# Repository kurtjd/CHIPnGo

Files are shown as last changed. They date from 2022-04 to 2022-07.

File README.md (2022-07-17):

# CHIPnGo
|Current Status|
|--------------|
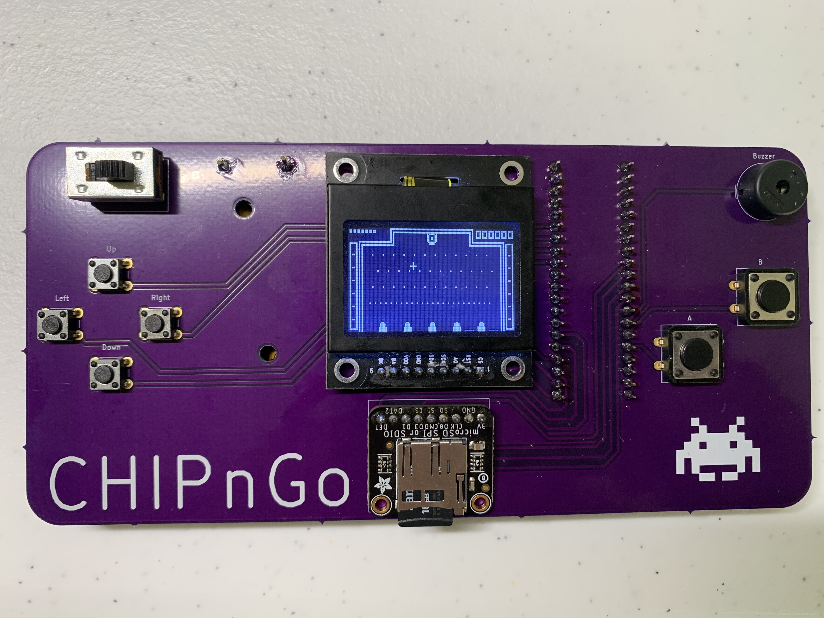
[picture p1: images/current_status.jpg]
||

Recently I've taken a serious interest in embedded development, so I decided for my first project I would attempt to port my [CHIP-8 emulator](https://github.com/kurtjd/jaxe) to a STM32 microcontroller in order to eventually build a CHIP-8 hand-held gaming console. Since this is being done as a learning experience, I also decided I would do this bare-metal with no libraries and write all drivers from scratch. While this is proving to be slow and extremely frustrating at times, it has also been very insightful and I've already learned a ton in such a short time.

[See it in action!](https://www.youtube.com/watch?v=SVods0DDVes)

## Build Guide
If you are interested in building your own CHIPnGo, check out [this guide](https://kurtjd.github.io/2022/07/16/chipngo-build-guide/).

## Development Blog
If you are interested in reading about my development of the project, some challenges I faced, and the bone-headed design decisions I made along the way due to my inexperience, check out my [dev blog](https://kurtjd.github.io/2022/07/08/chipngo-dev-1-intro/).

## Features
- Fully supports all CHIP-8 and S-CHIP ROMs
- LCD graphical display
- Four directional buttons and two action buttons
- Piezo buzzer for simple tone generation
- SD card reader for quick loading of any CHIP-8 ROM
- Battery power
- [Desktop application to manage ROMs on an SD card (aka game cartridge)](tools/cartridge8/)

## ToDo
- Improve startup menu for user to select ROM via SD card (make a bit more pretty)
- Improve startup splash screen (want something cool and animated)
- Iron out minor firmware bugs

## Limitations
Although my original emulator also has full support for XO-CHIP roms, I decided to focus on just CHIP-8 and S-CHIP for now for several reasons:
- XO-CHIP ROMs expect up to 64kb of memory, as opposed to 4kb expected by original CHIP-8 ROMs.
- XO-CHIP supports up to three colors, which would mean needing to move beyond a simple monochrome display.
- XO-CHIP supports variable frequencies/tones whereas CHIP-8 ROMs can only produce a single frequency, which makes handling sound simple.

CHIP-8 supports 16 keys for input, however for design purposes, the console only has 6 buttons.
However, most games only use a few buttons so this isn't too much of an issue.

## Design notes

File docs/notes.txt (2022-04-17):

CHIPnGo
-------
Handheld CHIP8 game console using JAXE emulator

To-Do
-----
-Write SPI driver
-Use Nokia 5110 for display testing
-Wire up actual display
-Write driver for actual display
-Test throughly
-Wire in buzzer
-Write code to generate sound
-Wire in SD reader
-Write SD reader driver
-Write code to read ROMs and configs from SD
-Write code to save userflags in Flash memory
-Write menu, boot splash, etc
-Figure out battery power situation
-Add switch to turn board on/off
-Look into prototype board to solder all together
-Look into building case

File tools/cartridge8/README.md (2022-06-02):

# Cartridge8
|ROM Selection|ROM Edit|
|---|---|
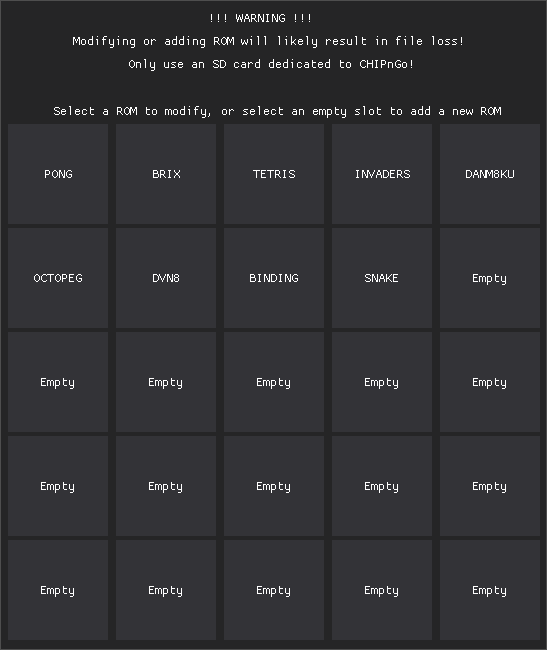
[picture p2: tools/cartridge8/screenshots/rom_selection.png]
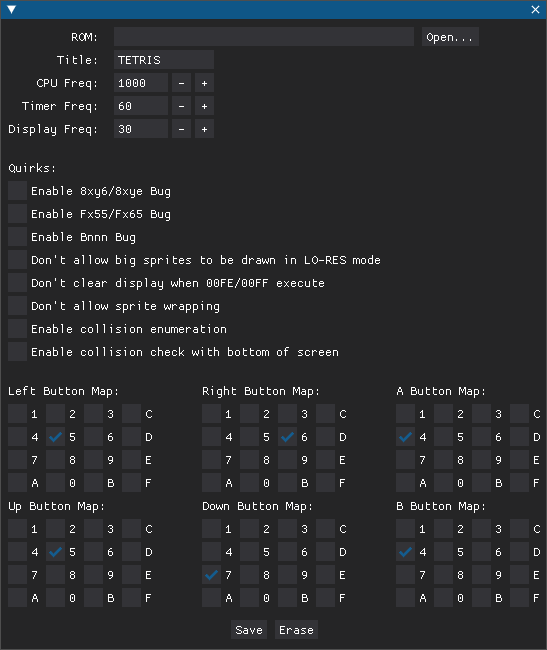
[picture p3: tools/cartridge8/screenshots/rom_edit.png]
|||

A tool for adding and configuring CHIP-8 ROMs to an SD card (aka game cartridge)
 for use by the CHIPnGo game console.
 
 ## Requirements
 - Python 3+
 - All requirements in requirements.txt
 
 ## Installation
 ```pip install -r requirements.txt```
 
 ## Run
 ```python cartridge8.py <path-to-SD-card>```
 
 ## Instructions
 - Insert an SD card (dedicated to CHIPnGo, see Warning) before running
 - After starting script, you will be presented with a ROM selection window
 - Select an existing ROM to modify, or an Empty slot to add a new ROM
 - Click Save to write your changes to SD, or Erase to erase the ROM from the SD
 
 ## WARNING
 This tool performs raw writes to your SD card and disregards any kind of file system already on there. 
 Thus, existing files are likely to be erased or corrupted after using this tool. ONLY use an SD card dedicated to 
 CHIPnGo to avoid data loss!

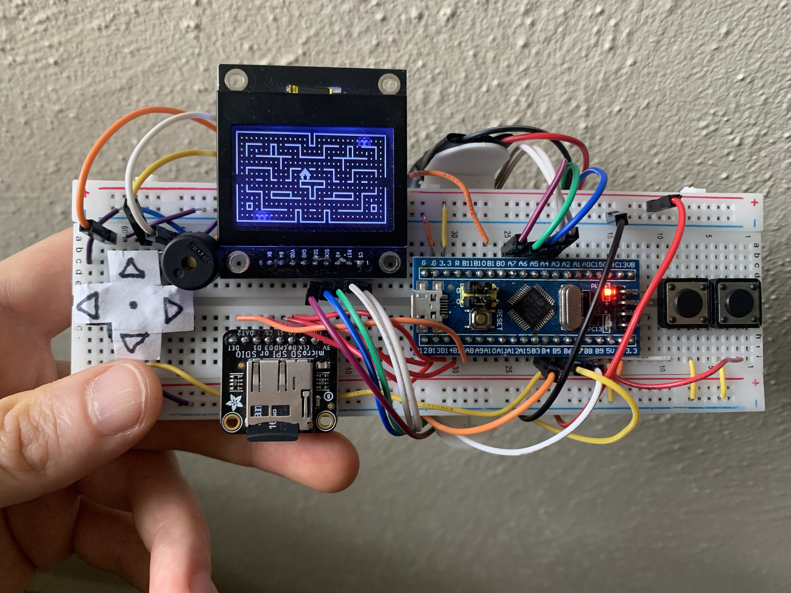
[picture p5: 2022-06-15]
images/current_status_6.jpg

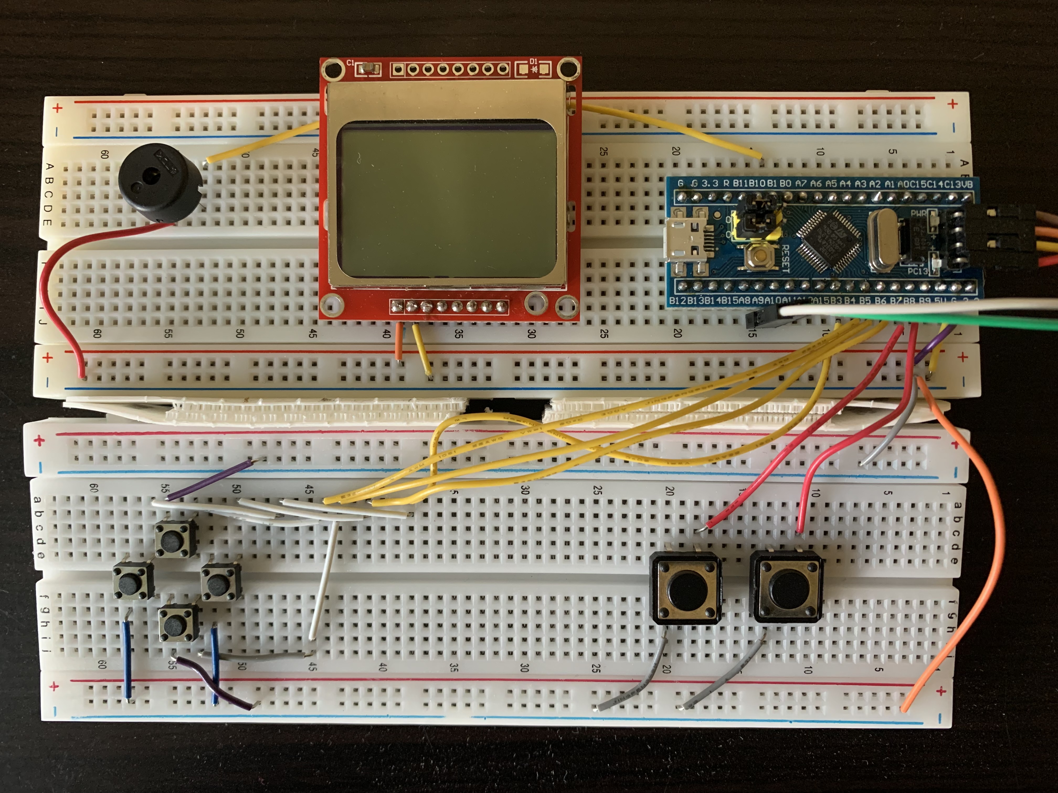
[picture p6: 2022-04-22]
images/current_status_2.jpg

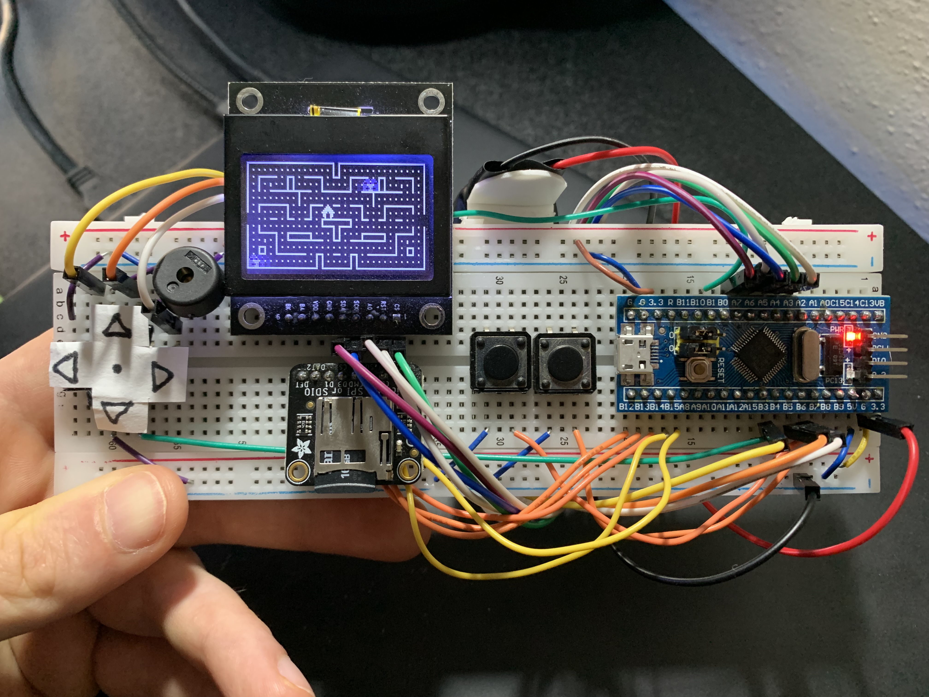
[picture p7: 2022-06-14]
images/current_status_5.jpg

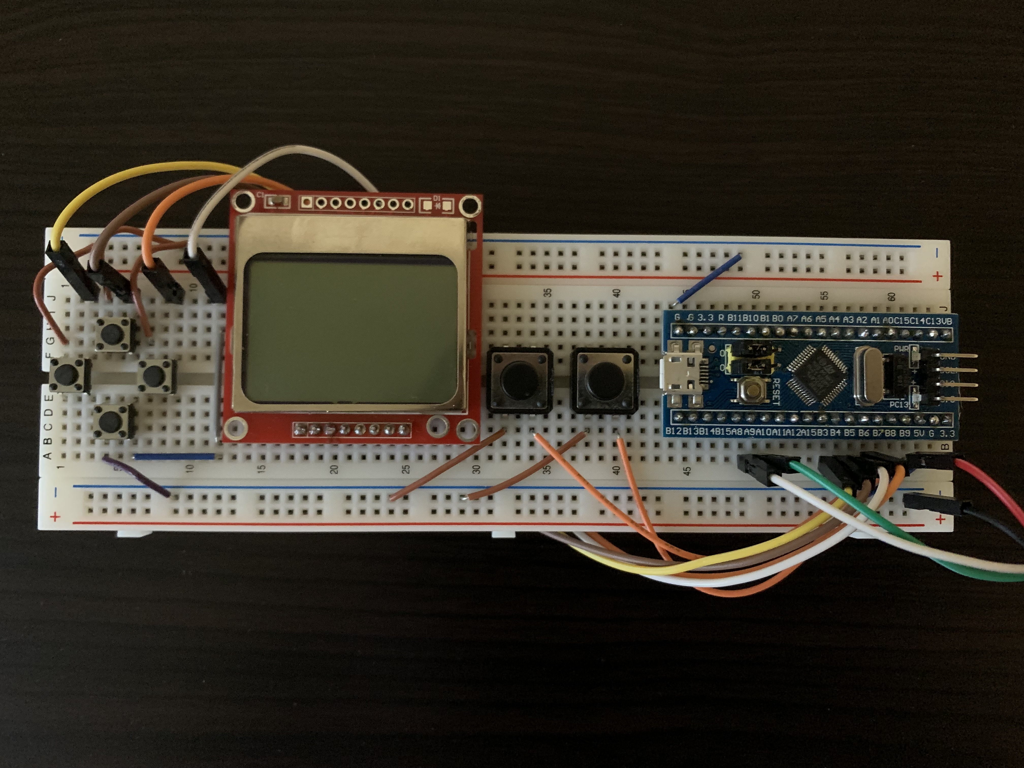
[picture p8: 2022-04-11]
images/current_status_1.jpg

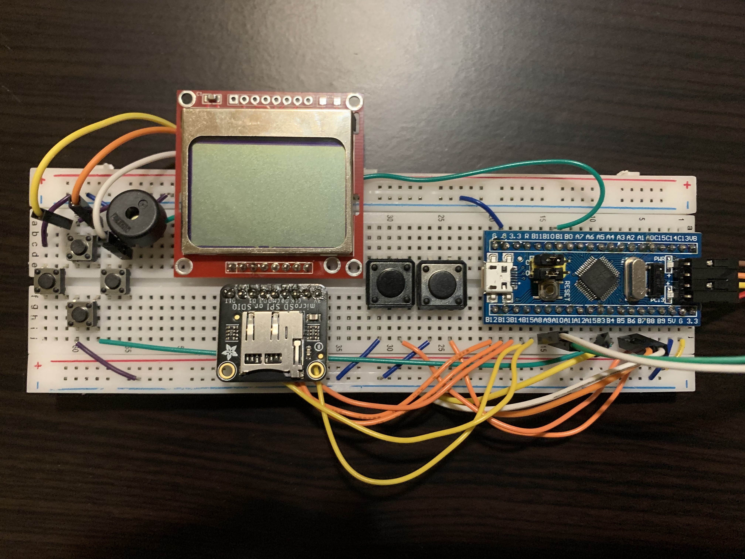
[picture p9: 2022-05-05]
images/current_status_3.jpg

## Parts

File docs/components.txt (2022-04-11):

Board: STM32F103 ($4)
Display: 1.5" 128x64 SPI ($4)
SD Reader:
Battery:
Case:
Piezo Buzzer:
Buttons: ($0.75)
Switch:
LED:
Wire:
Resistors:

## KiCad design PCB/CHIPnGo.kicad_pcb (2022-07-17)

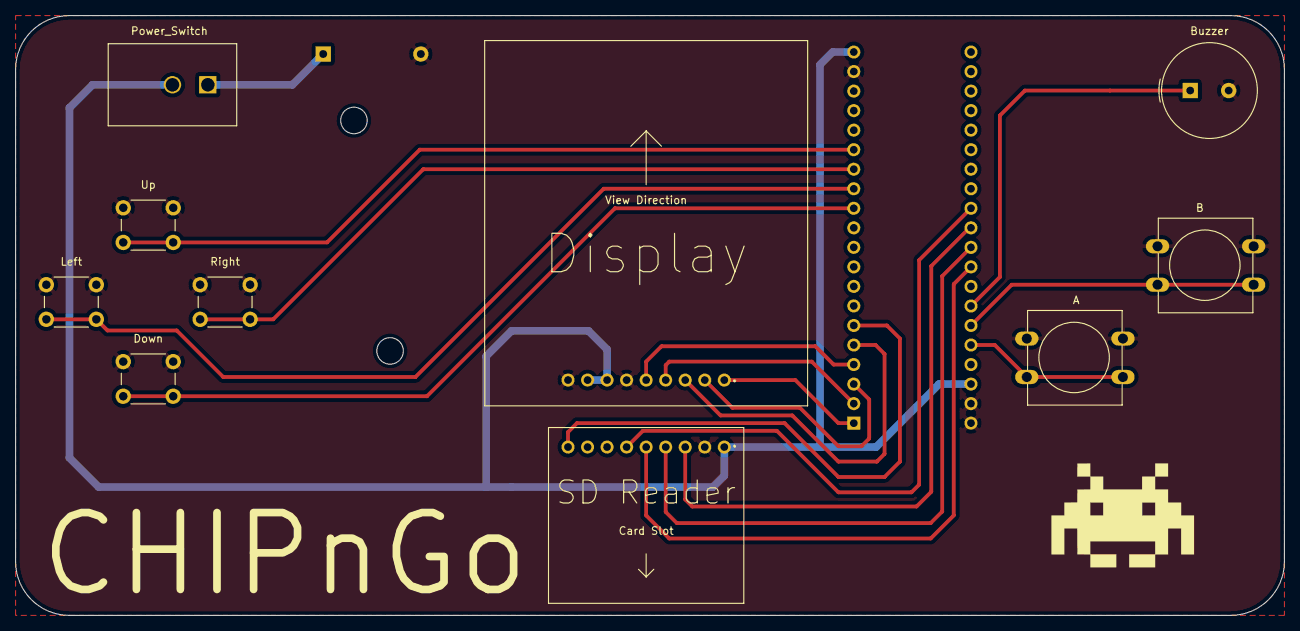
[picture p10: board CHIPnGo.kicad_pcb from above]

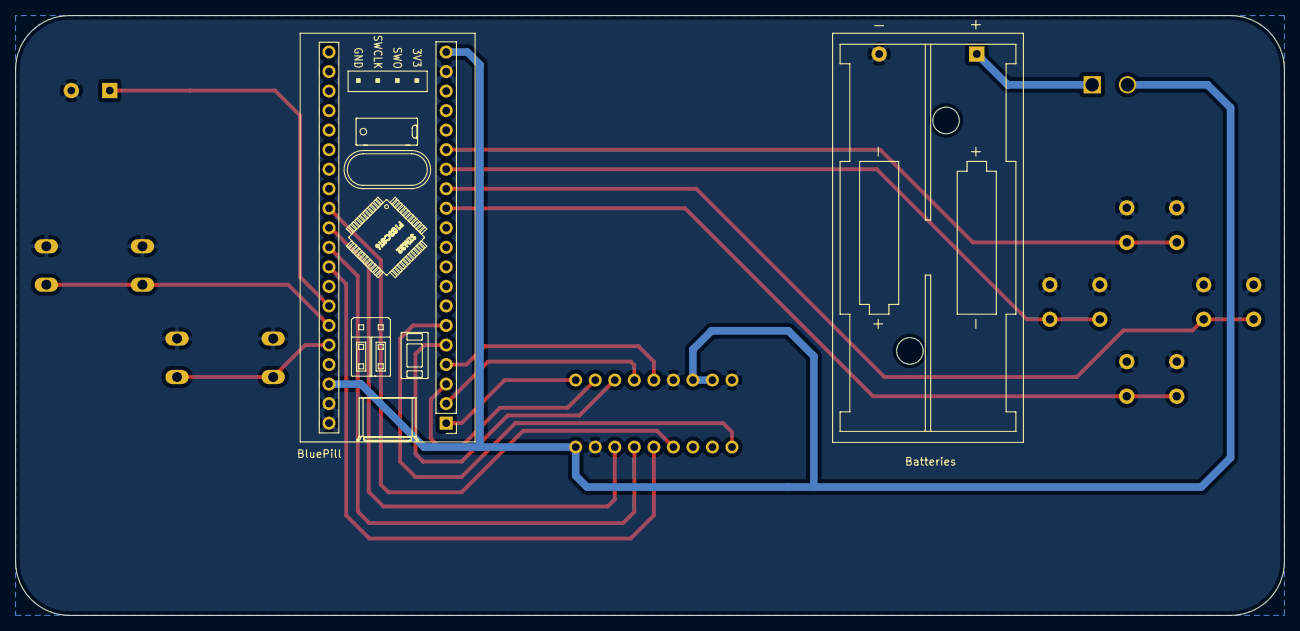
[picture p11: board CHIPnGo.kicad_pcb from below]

Board: 2 copper layers, 165.0 x 78.0 mm, 12 parts (2 on the bottom side), 20 nets.

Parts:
A: A_Btn; SW_PUSH-12mm
B: B_Btn; SW_PUSH-12mm
Batteries: Batteries; BatteryHolder_Keystone_2468_2xAAA
BluePill: STM32_BluePill; YAAJ_BluePill_1
Buzzer: Piezo_Buzzer; Buzzer_TDK_PS1240P02BT_D12.2mm_H6.5mm
Display: ERM12864-8_Display; ERM12864
Down: Down_Btn; SW_PUSH_6mm_H5mm
Left: Left_Btn; SW_PUSH_6mm_H5mm
Power_Switch: Power_Switch; GF-123-0054
Right: Right_Btn; SW_PUSH_6mm_H5mm
SD Reader: Adafruit_MicroSD_Breakout; Adafruit_SD_Reader
Up: Up_Btn; SW_PUSH_6mm_H5mm

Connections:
+3V3: BluePill.20, BluePill.38, Display.7, Display.8, Power_Switch.2, SD Reader.1
/Card_Det: BluePill.6, SD Reader.9
GND: A.2, B.2, Batteries.2, BluePill.19, BluePill.39, BluePill.40, Buzzer.2, Display.6, Display.9, Down.1, Left.1, Right.1, SD Reader.2, Up.1
unnamed: Batteries.1, Power_Switch.1
unnamed: BluePill.34, Buzzer.1
unnamed: BluePill.13, Left.2
unnamed: BluePill.12, Down.2
unnamed: BluePill.15, Up.2
unnamed: BluePill.14, Right.2
unnamed: A.1, BluePill.36
unnamed: B.1, BluePill.35
unnamed: BluePill.30, SD Reader.3
unnamed: BluePill.31, SD Reader.4
unnamed: BluePill.32, SD Reader.5
unnamed: BluePill.29, SD Reader.6
unnamed: BluePill.1, Display.1
unnamed: BluePill.2, Display.4
unnamed: BluePill.3, Display.2
unnamed: BluePill.4, Display.5
unnamed: BluePill.5, Display.3

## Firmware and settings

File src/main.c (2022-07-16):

#include <stdbool.h>
#include <stdint.h>
#include <stdio.h>
#include <string.h>

#include "buttons.h"
#include "chip8.h"
#include "clock.h"
#include "delay.h"
#include "display.h"
#include "gpio.h"
#include "led.h"
#include "pwm.h"
#include "sd.h"
#include "sysclk.h"
#include "uart.h"

#define MAX_ROMS 25

// Emulator (TODO: Put this all in struct)
CHIP8 chip8;
uint8_t metadata[SD_BLOCK_SIZE] = {0};
char title[11];
uint32_t cpu_freq = CPU_FREQ_DEFAULT;
uint32_t timer_freq = TIMER_FREQ_DEFAULT;
uint32_t refresh_freq = REFRESH_FREQ_DEFAULT;
bool quirks[NUM_QUIRKS] = {0, 0, 0, 0, 0, 0, 0, 0};
uint16_t BTN_LEFT_MAP = 0x90;
uint16_t BTN_RIGHT_MAP = 0x240;
uint16_t BTN_UP_MAP = 0x20;
uint16_t BTN_DOWN_MAP = 0x100;
uint16_t BTN_A_MAP = 0x00;
uint16_t BTN_B_MAP = 0x40;
bool play_sound = false;
int rom_num = 0;

// A basic splash screen that waits for user to press A
void show_splash(void) {
    display_print(37, 4, "CHIP N GO");
    // display_print(20, 4, "PRESS A TO PLAY");
    // display_print(20, 7, "CREATED BY KURT");

    for (int i = 0; i < 10; i++) {
        pwm_start();
        delay(100);
        pwm_stop();
        delay(100);
    }

    display_clear();

    // while (!btn_released(BTN_A));
    // delay(2000);
}

void btn_to_key(uint16_t btn_map, CHIP8K action) {
    for (int i = 0; i < 16; i++) {
        if (btn_map & 1)
            chip8.keypad[i] = action;
        btn_map >>= 1;
    }
}

void parse_quirks(uint8_t q) {
    for (int i = 0; i < 8; i++) {
        quirks[i] = q & 1;
        q >>= 1;
    }
}

// Set up the emulator to begin running.
bool init_emulator(void) {
    chip8_init(&chip8, cpu_freq, timer_freq, refresh_freq, PC_START_ADDR_DEFAULT,
               quirks, metadata, rom_num);
    chip8_load_font(&chip8);

    return true;
}

void load_rom(int rom_num) {
    uint32_t start_sector = rom_num * 8;
    sd_read_block(start_sector, metadata);
    sd_read_blocks(start_sector + 1, chip8.RAM + PC_START_ADDR_DEFAULT, 7);
}

bool process_metadata(void) {
    if (metadata[0] == 0xC8) {
        strcpy(title, (char *)(&metadata[1]));

        cpu_freq = (metadata[12] << 24) | (metadata[13] << 16) | (metadata[14] << 8) | (metadata[15]);
        timer_freq = metadata[16];
        refresh_freq = metadata[17];

        parse_quirks(metadata[18]);

        BTN_LEFT_MAP = (metadata[19] << 8) | (metadata[20]);
        BTN_RIGHT_MAP = (metadata[21] << 8) | (metadata[22]);
        BTN_UP_MAP = (metadata[23] << 8) | (metadata[24]);
        BTN_DOWN_MAP = (metadata[25] << 8) | (metadata[26]);
        BTN_A_MAP = (metadata[27] << 8) | (metadata[28]);
        BTN_B_MAP = (metadata[29] << 8) | (metadata[30]);

        return true;
    }

    return false;
}

// Very slow... but functional for now
bool seek_rom(int dir) {
    int attempts = 0;

    do {
        if (rom_num >= MAX_ROMS)
            rom_num = 0;
        else if (rom_num < 0)
            rom_num = MAX_ROMS - 1;

        load_rom(rom_num);
        rom_num += dir;

        attempts++;
    } while (attempts <= MAX_ROMS && !process_metadata());

    if (attempts <= MAX_ROMS) {
        rom_num -= dir;
        return true;
    }

    // No ROM exists if we attempted to find a ROM more than MAX_ROMS times
    return false;
}

void select_rom(void) {
    int scan_dir = 1;
    bool rom_exists = seek_rom(scan_dir);

    while (rom_exists) {
        display_clear();
        display_print(36 + ((10 - strlen(title)) * 2), 3, title);
        display_print(2, 4, "<                   >");
        display_print(19, 5, "PRESS A TO PLAY");

        scan_dir = 0;
        while (!scan_dir) {
            if (btn_released(BTN_A)) {
                pwm_start();
                delay(500);
                pwm_stop();
                return;
            } else if (btn_released(BTN_RIGHT))
                scan_dir = 1;
            else if (btn_released(BTN_LEFT))
                scan_dir = -1;
        }
        rom_num += scan_dir;

        pwm_start();
        delay(1);
        pwm_stop();

        rom_exists = seek_rom(scan_dir);
    }

    // No ROM exists on game cartridge
    // Just hang since no way to recover
    display_clear();
    display_print(25, 4, "ROM NOT FOUND");
    while (1)
        ;
}

// Makes the physical screen match the emulator display.
void draw_display(void) {
    display_draw(chip8.display);
}

// Handles sound.
void handle_sound(void) {
    if (!play_sound && chip8.beep) {
        pwm_start();
        play_sound = true;
    } else if (play_sound && !chip8.beep) {
        pwm_stop();
        play_sound = false;
    }
}

// Handles drawing the display.
void handle_display(void) {
    if (chip8.display_updated) {
        draw_display();
    }
}

// Checks for key presses/releases and a quit event.
void handle_input(void) {
    if (btn_pressed(BTN_LEFT))
        btn_to_key(BTN_LEFT_MAP, KEY_DOWN);
    if (btn_pressed(BTN_UP))
        btn_to_key(BTN_UP_MAP, KEY_DOWN);
    if (btn_pressed(BTN_DOWN))
        btn_to_key(BTN_DOWN_MAP, KEY_DOWN);
    if (btn_pressed(BTN_RIGHT))
        btn_to_key(BTN_RIGHT_MAP, KEY_DOWN);
    if (btn_pressed(BTN_A))
        btn_to_key(BTN_A_MAP, KEY_DOWN);
    if (btn_pressed(BTN_B))
        btn_to_key(BTN_B_MAP, KEY_DOWN);

    if (btn_released(BTN_LEFT))
        btn_to_key(BTN_LEFT_MAP, KEY_RELEASED);
    if (btn_released(BTN_UP))
        btn_to_key(BTN_UP_MAP, KEY_RELEASED);
    if (btn_released(BTN_DOWN))
        btn_to_key(BTN_DOWN_MAP, KEY_RELEASED);
    if (btn_released(BTN_RIGHT))
        btn_to_key(BTN_RIGHT_MAP, KEY_RELEASED);
    if (btn_released(BTN_A))
        btn_to_key(BTN_A_MAP, KEY_RELEASED);
    if (btn_released(BTN_B))
        btn_to_key(BTN_B_MAP, KEY_RELEASED);
}

void echo_sd_read(uint32_t addr) {
    uint8_t data[SD_BLOCK_SIZE * 2] = {0};
    sd_read_blocks(addr, data, 2);

    for (int i = 0; i < SD_BLOCK_SIZE * 2; i++) {
        char msg[7] = {0};
        sprintf(msg, "0x%02X ", data[i]);

        if ((i + 1) % 16 == 0)
            msg[5] = '\n';

        uart_write_str(msg);
    }

    uart_write('\n');
}

void handle_sd() {
    // Wait for user to insert SD card
    if (!sd_inserted()) {
        display_print(2, 4, "INSERT GAME CARTRIDGE");
        while (!sd_inserted())
            ;

        // Wait briefly for SD to be fully inserted
        display_clear();
        delay(100);
    }

    // Can't recover so just hang and tell the user to restart
    if (!sd_init()) {
        display_print(5, 3, "GAME CARTRIDGE ERROR");
        display_print(22, 4, "PLEASE RESTART");
        while (1)
            ;
    }
}

int main(void) {
    set_sysclk(72);

    gpio_init(GPIOA);
    gpio_init(GPIOB);
    led_enable();

    pwm_init(880);

    display_init();
    show_splash();

    handle_sd();

    buttons_init();

    clock_start();

    select_rom();
    init_emulator();

    while (1) {
        handle_input();
        chip8_cycle(&chip8);
        handle_sound();
        handle_display();

        // Exit gets set true if the ROM calls the exit command
        if (chip8.exit)
            chip8_reset(&chip8);
    }

    return 0;
}

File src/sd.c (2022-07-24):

#include "sd.h"

#include <stdlib.h>

#include "delay.h"
#include "gpio.h"

// CS: A4
// SCK: A5
// MISO: A6 // PUR needed? Probably not since using breakout
// MOSI: A7 // Keep high during read transfer (after sending command)?
// Det: A9

#define SPI_CLK (1 << 12)
#define SPI1_START 0x40013000
#define SPI1_CR1 (*((volatile uint32_t *)(SPI1_START + 0x00)))
#define SPI1_CR2 (*((volatile uint32_t *)(SPI1_START + 0x04)))
#define SPI1_SR (*((volatile uint32_t *)(SPI1_START + 0x08)))
#define SPI1_DR (*((volatile uint32_t *)(SPI1_START + 0x0C)))

#define RESET_DUMMY_CYCLES 10
#define START_BITS 0x40
#define STOP_BITS 0x01
#define NUM_ARGS 4
#define NUM_R3_RESP_BYTES 5
#define READ_BYTE_DELAY 8
#define CARD_IDLE 1
#define CMD_OK 0
#define RW_OK 0xFE
#define DATA_ACCEPTED 2
#define INIT_MAX_ATTEMPTS 10000
#define READ_MAX_ATTEMPTS 10000

struct command {
    uint8_t cmd_bits;
    uint8_t args[NUM_ARGS];
    uint8_t crc;
};

const struct command GO_IDLE_STATE = {
    0,
    {0x00, 0x00, 0x00, 0x00},
    0x4A};

const struct command SEND_IF_COND = {
    8,
    {0x00, 0x00, 0x01, 0xAA},
    0x43};

const struct command APP_CMD = {
    55,
    {0x00, 0x00, 0x00, 0x00},
    0xFF};

const struct command SD_SEND_OP_COND = {
    41,
    {0x40, 0x00, 0x00, 0xA0},
    0xFF};

const struct command READ_OCR = {
    58,
    {0x00, 0x00, 0x00, 0x00},
    0xFF};

const struct command READ_SINGLE_BLOCK = {
    17,
    {0x00, 0x00, 0x00, 0x00},  // These will be replaced by addr bytes
    0xFF};

const struct command READ_MULTIPLE_BLOCK = {
    18,
    {0x00, 0x00, 0x00, 0x00},  // These will be replaced by addr bytes
    0xFF};

const struct command STOP_TRANSMISSION = {
    12,
    {0x00, 0x00, 0x00, 0x00},
    0xFF};

const struct command WRITE_BLOCK = {
    24,
    {0x00, 0x00, 0x00, 0x00},  // These will be replaced by addr bytes
    0xFF};

const struct command WRITE_MULTIPLE_BLOCK = {
    25,
    {0x00, 0x00, 0x00, 0x00},  // These will be replaced by addr bytes
    0xFF};

static void _gpio_init(void) {
    // Disable reset state
    GPIOA_CRL &= ~((1 << 18) | (1 << 22) | (1 << 30));

    // MODEy (4, 5, 7 2MHz out, 6 in)
    GPIOA_CRL |= ((1 << 17) | (1 << 21) | (1 << 29));

    // CNFy (5, 7 alt out, 6 floating in)
    GPIOA_CRL |= ((1 << 23) | (1 << 31));
}

static void _spi_init1(void) {
    RCC_APB2ENR |= SPI_CLK;
    for (volatile int i = 0; i < 10; i++)
        ;

    // CLK / 256
    // SD must be initialized with a clk speed of between 100-400KHz
    // When CPU clock is set to 72MHz, APB2 clock is set to 72Mhz
    // 72MHz / 256 equals roughly 280KHz
    SPI1_CR1 |= (7 << 3);

    SPI1_CR1 |= (1 << 9);  // Enable software CS
    SPI1_CR2 |= (1 << 2);  // Enable CS output
    SPI1_CR1 |= (1 << 2);  // Set as master
    SPI1_CR1 |= (1 << 6);  // Enable
}

static void _spi_init2(void) {
    // Wait for SPI to finish up then disable it
    delay(10);
    SPI1_CR1 &= ~(1 << 6);

    // Change CS pin to alt function output
    GPIOA_CRL |= (1 << 19);

    // Change the frequency to something much faster
    SPI1_CR1 &= ~(7 << 3);  // Erase old freq settings
    SPI1_CR1 |= (1 << 5);   // CLK / 32 (might be able to go faster)

    SPI1_CR1 &= ~(1 << 9);  // Disable software CS (thus enabling hardware CS)
    SPI1_CR1 |= (1 << 6);   // Re-enable SPI
}

static void _sd_write(uint8_t data) {
    SPI1_DR = data;
    while (!(SPI1_SR & 0x02))
        ;
}

static uint8_t _sd_read(void) {
    return SPI1_DR;
}

static void _dummy_write(int n) {
    for (int i = 0; i < n; i++)
        _sd_write(0xFF);
}

static void _rest(void) {
    // Wait until SD is sending out a constant high signal which means ready
    while (_sd_read() != 0xFF)
        _dummy_write(1);
}

static uint8_t _read_R1(void) {
    /* Must keep writing until receive a valid response,
     * or 8 bytes have been written (max time a response can take)
     * We detect a valid response by looking for a 0 in the 8th bit */
    uint8_t resp = _sd_read();
    for (int i = 0; i < READ_BYTE_DELAY && (resp & (1 << 7)); i++) {
        _dummy_write(1);
        resp = _sd_read();
    }

    return resp;
}

static const uint8_t *_read_R3(void) {
    static uint8_t resp[NUM_R3_RESP_BYTES];

    // First read the response byte. Then read in data bytes.
    resp[0] = _read_R1();
    for (int i = 1; i < NUM_R3_RESP_BYTES; i++) {
        _dummy_write(1);
        resp[i] = _sd_read();
    }

    return resp;
}

static void _power_on(void) {
    GPIOA_ODR |= (1 << 4);  // Set CS high

    // Send >74 dummy clocks with MOSI high
    _dummy_write(RESET_DUMMY_CYCLES);

    // Stabilize
    delay(10);
}

static void _send_cmd(const struct command *cmd, const uint8_t *args) {
    // Wait for SD to be ready to receive command
    _rest();

    // The full command byte must start with the start bits
    _sd_write(START_BITS | cmd->cmd_bits);

    // Send arguments
    // Use default arguments if none provided
    for (int i = 0; i < NUM_ARGS; i++) {
        if (args)
            _sd_write(args[i]);
        else
            _sd_write(cmd->args[i]);
    }

    // The full CRC byte must end with the stop bits
    _sd_write((cmd->crc << 1) | STOP_BITS);
}

static bool _reset(void) {
    // Some garbage comes in on MISO when MCU is reset without power loss
    // So do a few writes to discard it
    // TODO: Maybe come up with more elegant way to handle this
    _dummy_write(3);

    _send_cmd(&GO_IDLE_STATE, NULL);

    // Ensure SD is now in idle state
    return _read_R1() == CARD_IDLE;
}

static bool _verify(void) {
    _send_cmd(&SEND_IF_COND, NULL);

    // If the last byte is 0xAA (which means our card is SD2+), SD card is good
    return _read_R3()[NUM_R3_RESP_BYTES - 1] == 0xAA;
}

static bool _initialize(void) {
    /* The below sequence begins the SD initilization process.
     * It must be repeated until R1 returns 0
     * (signifying SD is no longer idle and ready to accept all commands) */
    int attempts = 0;
    do {
        _send_cmd(&APP_CMD, NULL);
        _read_R1();
        _send_cmd(&SD_SEND_OP_COND, NULL);
        attempts++;
    } while (attempts < INIT_MAX_ATTEMPTS && _read_R1() == CARD_IDLE);

    if (attempts >= INIT_MAX_ATTEMPTS)
        return false;

    _send_cmd(&READ_OCR, NULL);

    // Ensure SD is no longer idle and CCS is 1
    const uint8_t *resp = _read_R3();
    return ((resp[0] == CMD_OK) && (resp[1] & (1 << 6)));
}

static bool _wait_for_data_token(uint8_t token) {
    int attempts = 0;

    while (attempts < READ_MAX_ATTEMPTS && _sd_read() != token) {
        _dummy_write(1);
        attempts++;
    }

    return (attempts < READ_MAX_ATTEMPTS);
}

static bool _wait_for_data_resp(void) {
    uint8_t resp = _sd_read();
    while (resp == 0xFF) {
        _dummy_write(1);
        resp = _sd_read();
    }

    return ((resp >> 1) & 0x0F) == DATA_ACCEPTED;
}
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

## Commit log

2022-04-11 Add current status image
2022-04-11 Begin writing SPI driver
2022-04-17 SPI Stuff
2022-04-22 Create basic PWM driver
2022-04-22 Add sound support (via PWM to a piezo buzzer)
    [chip8.h, main.c]
2022-04-25 Change button to pin config
2022-04-25 Begin writing sd driver
2022-05-07 Implement basic display driver
2022-05-15 Lower SPI speed to seemingly fix display corruption
    [display.c]
2022-05-29 Add quirk parsing and fix input bug
    [chip8.h, display.c, main.c]
2022-06-05 Make input interrupt-driven as opposed to polling
2022-06-05 Change clock to use timer instead of systick
2022-06-05 Simplify timer
2022-06-15 Swap position of bluepill and buttons
2022-06-20 Change button input pins for cleaner PCB traces
2022-06-25 Change pins for SD and display for better trace routing
2022-07-03 Add PCB image
2022-07-17 Add PCB files
    [CHIPnGo.kicad_pcb, CHIPnGo.kicad_sch]

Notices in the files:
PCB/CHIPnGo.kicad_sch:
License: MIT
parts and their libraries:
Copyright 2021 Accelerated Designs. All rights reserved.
